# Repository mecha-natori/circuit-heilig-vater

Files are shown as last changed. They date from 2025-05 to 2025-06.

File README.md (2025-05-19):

# Heilig Vater

Heilig Vaterは[STM32F405RGT6]を使用した12V出力駆動用基板です。

## 仕様

| 機能 | 個数 | 備考 |
| :---: | ---: | :--- |
| MCU | 1 | [STM32F405RGT6] |
| ST-LINK | 1 | ピンアサインはSWD |
| CAN | 2 | 電源ピンは5V、Classic CANのみ対応、1系統から2個 |
| 12Vデジタル出力 | 14 | インジケータLED付き |
|  リセットスイッチ | 1 | |
| 5V-3.3Vレギュレータ | 1 | 外部電源からの供給用 |
| M.U氏の御尊顔 | 1 | 目が光る！(電源供給確認用(建前)) |
| 寸法(外形) | | 111mm x 86mm |
| 寸法(ネジ穴間) | | 100mm x 75mm |

## 名前の由来

**H**igh **V**oltageです。今回はひねくれてドイツ語にしてみました。\
Heilig Vater beobachtet dich.

## 使用フォント

- KiCad Font : シンボル名・部名
- Times New Roman : 右下基板名
- [UnifrakturMaguntia - Google Fonts] : 左下"Heilig Vater beobachtet dich."
- [機械彫刻用標準書体フォント] : その他テキスト

[stm32f405rgt6]: https://www.stmcu.jp/stm32/stm32f4/stm32f405415/12229
[unifrakturmaguntia - google fonts]: https://fonts.google.com/specimen/UnifrakturMaguntia
[機械彫刻用標準書体フォント]: https://font.kim

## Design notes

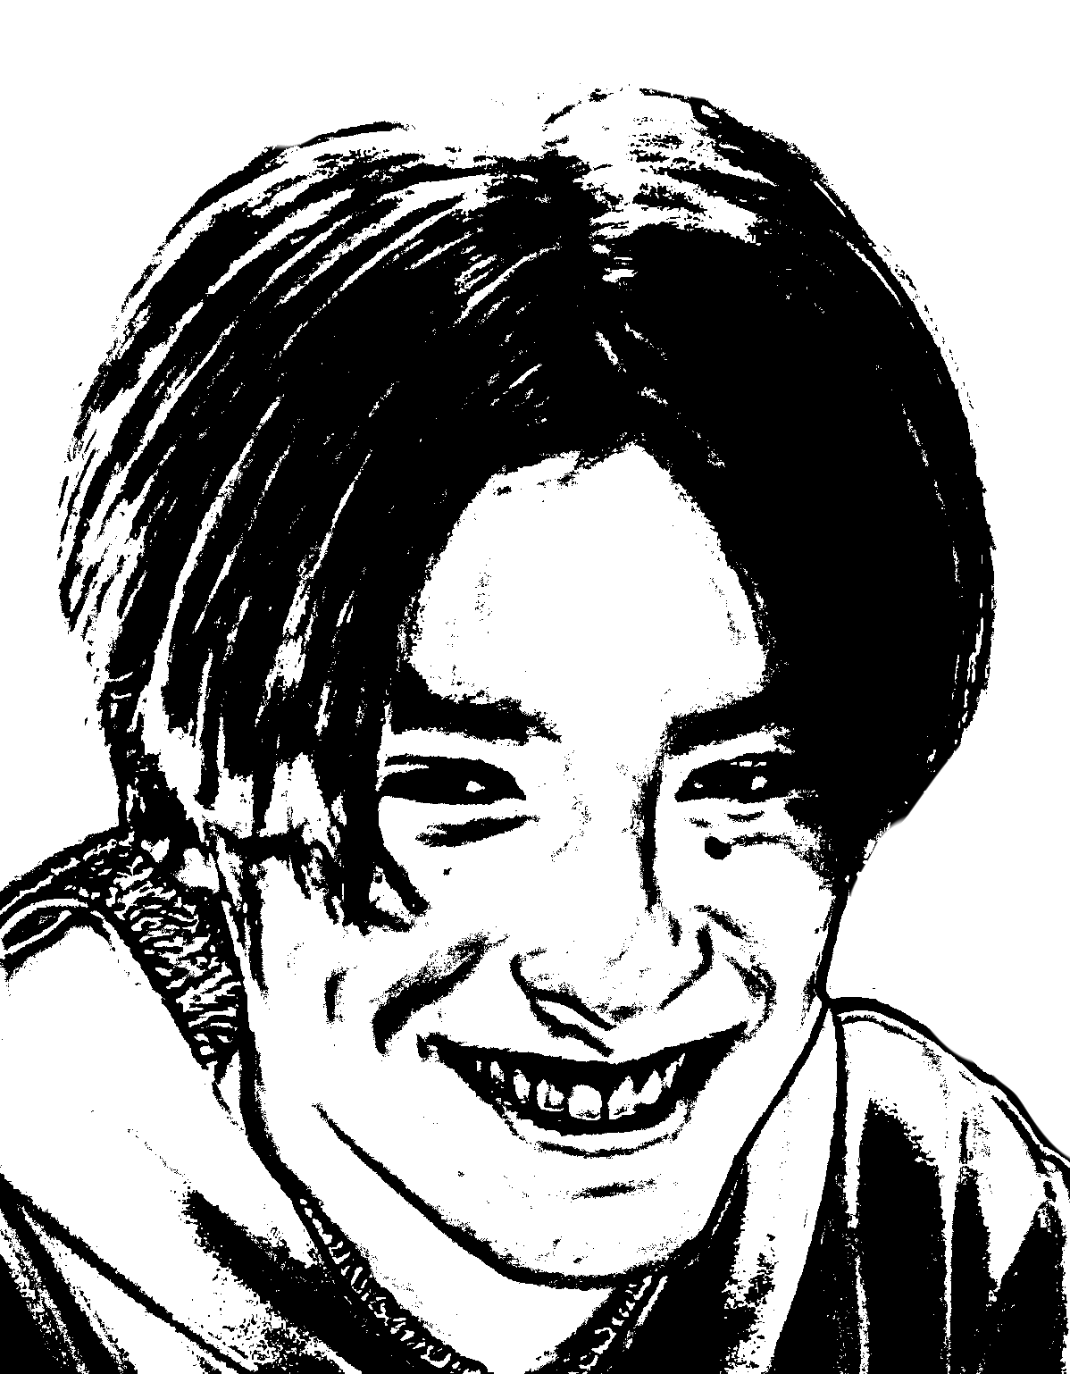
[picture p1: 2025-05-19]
m-u.png

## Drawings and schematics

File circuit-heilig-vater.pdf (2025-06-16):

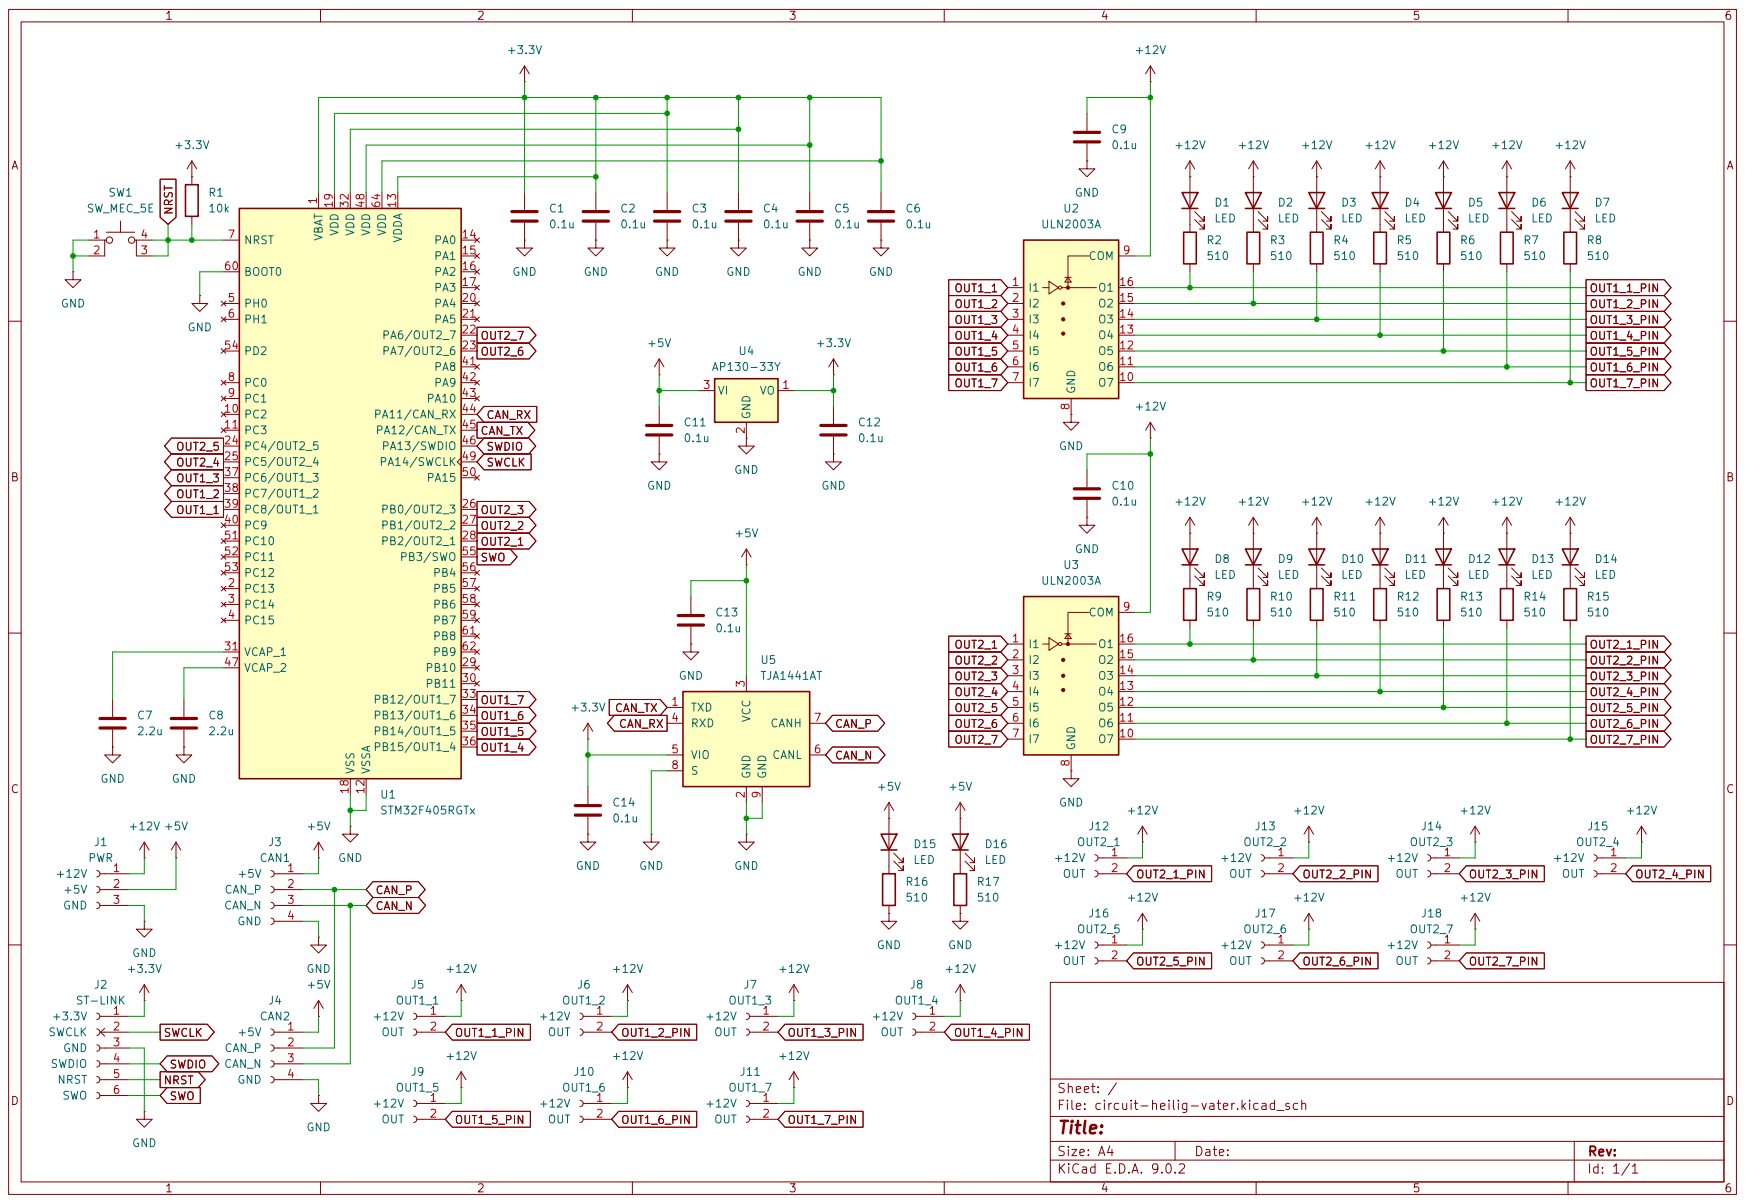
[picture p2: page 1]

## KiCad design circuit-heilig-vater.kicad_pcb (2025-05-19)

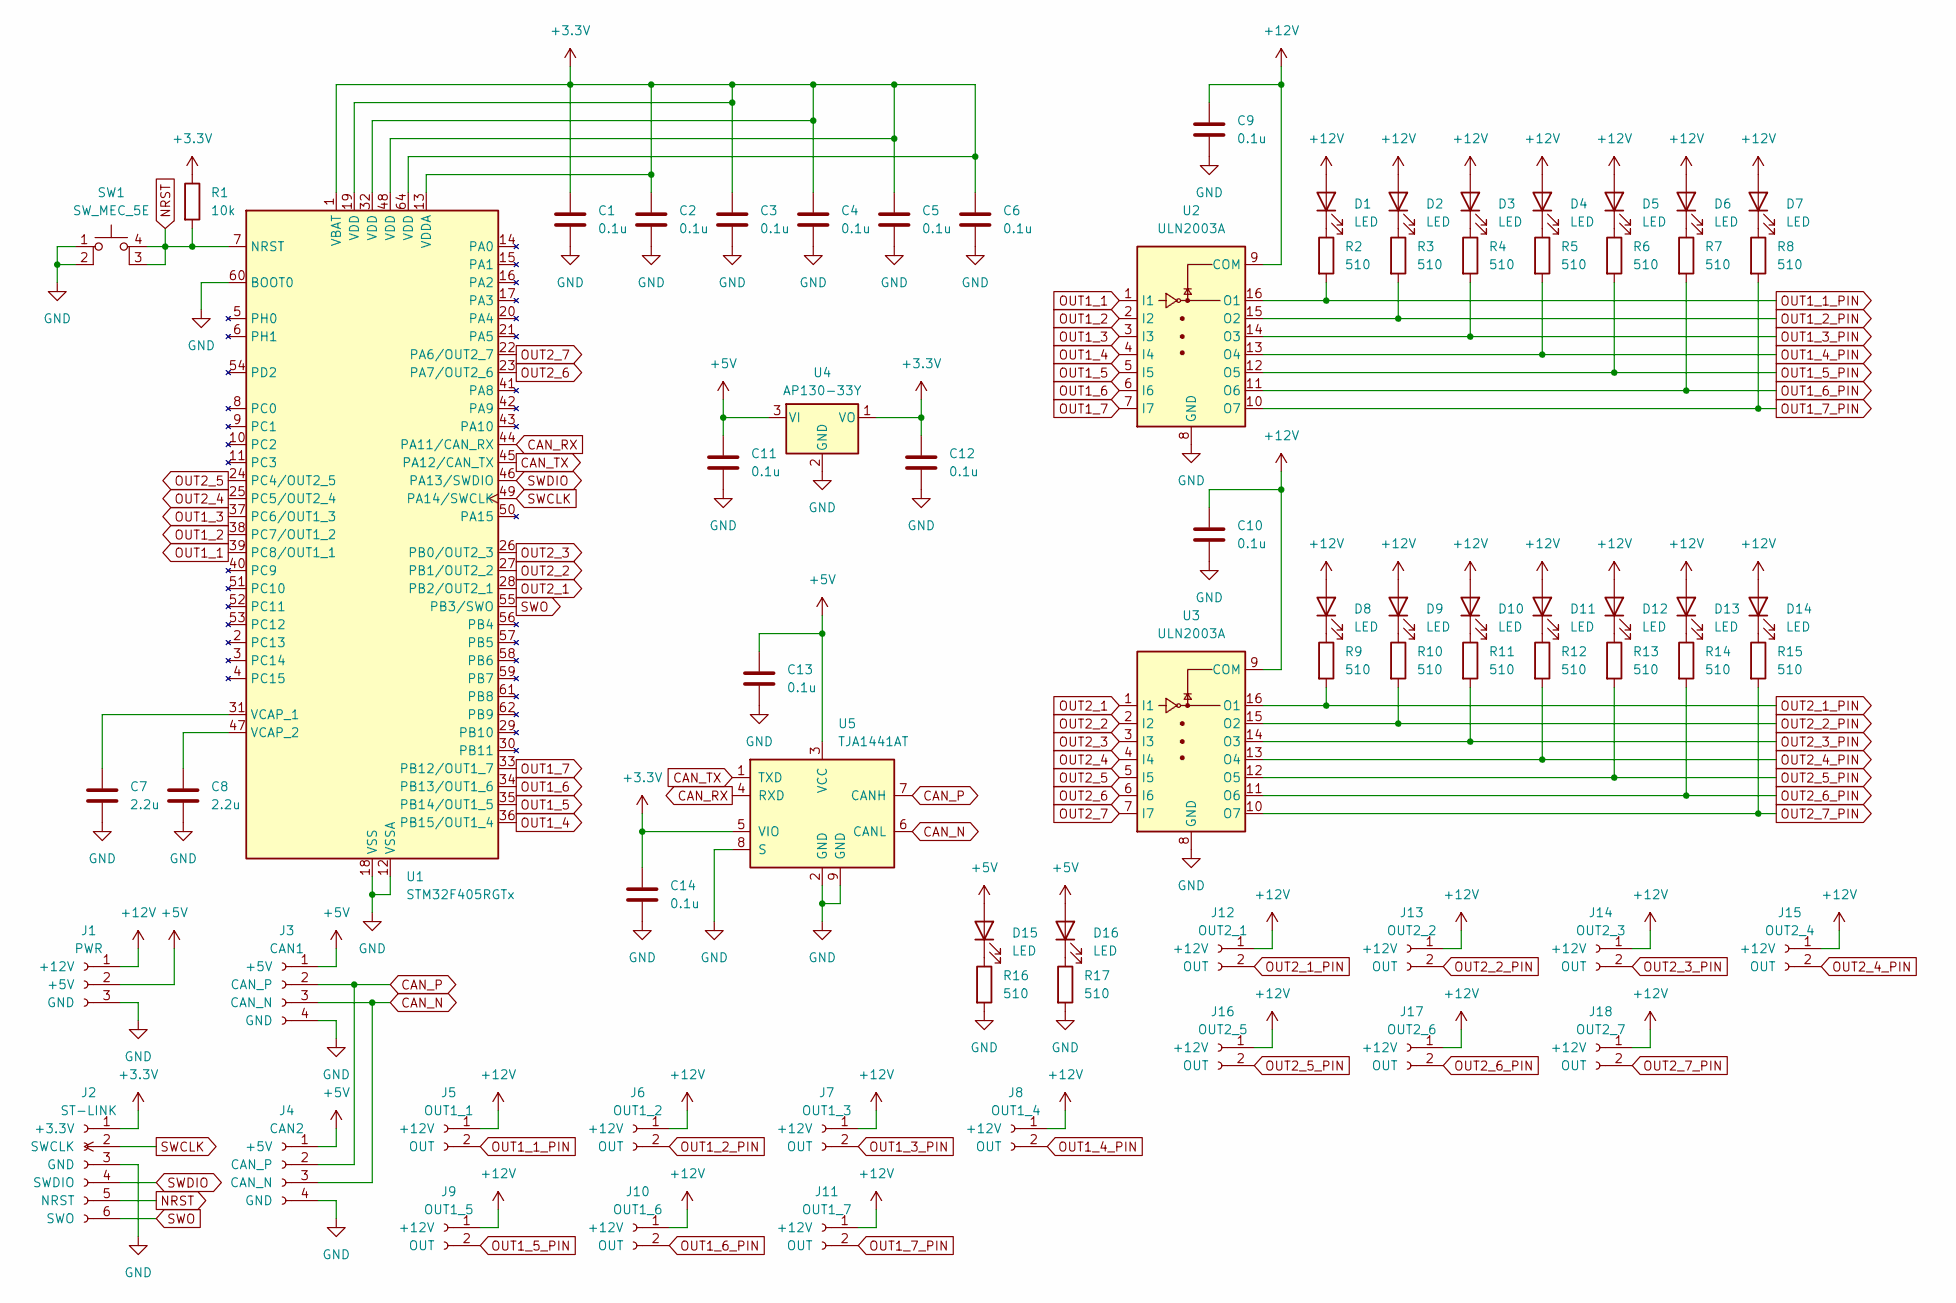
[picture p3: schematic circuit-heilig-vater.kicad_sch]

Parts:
C1, C2, C3, C4, C5, C6, C9, C10, C11, C12, C13, C14: 0.1u; C_0603_1608Metric_Pad1.08x0.95mm_HandSolder
C7, C8: 2.2u; C_0603_1608Metric_Pad1.08x0.95mm_HandSolder
D1, D2, D3, D4, D5, D6, D7, D8, D9, D10, D11, D12, D13, D14, D15, D16: LED; LED_0603_1608Metric_Pad1.05x0.95mm_HandSolder
J1: PWR; JST_XH_S3B-XH-A_1x03_P2.50mm_Horizontal
J2: ST-LINK; JST_ZH_B6B-ZR_1x06_P1.50mm_Vertical
J3: CAN1; JST_XA_B04B-XASK-1_1x04_P2.50mm_Vertical
J4: CAN2; JST_XA_B04B-XASK-1_1x04_P2.50mm_Vertical
J5: OUT1_1; JST_XH_B2B-XH-A_1x02_P2.50mm_Vertical
J6: OUT1_2; JST_XH_B2B-XH-A_1x02_P2.50mm_Vertical
J7: OUT1_3; JST_XH_B2B-XH-A_1x02_P2.50mm_Vertical
J8: OUT1_4; JST_XH_B2B-XH-A_1x02_P2.50mm_Vertical
J9: OUT1_5; JST_XH_B2B-XH-A_1x02_P2.50mm_Vertical
J10: OUT1_6; JST_XH_B2B-XH-A_1x02_P2.50mm_Vertical
J11: OUT1_7; JST_XH_B2B-XH-A_1x02_P2.50mm_Vertical
J12: OUT2_1; JST_XH_B2B-XH-A_1x02_P2.50mm_Vertical
J13: OUT2_2; JST_XH_B2B-XH-A_1x02_P2.50mm_Vertical
J14: OUT2_3; JST_XH_B2B-XH-A_1x02_P2.50mm_Vertical
J15: OUT2_4; JST_XH_B2B-XH-A_1x02_P2.50mm_Vertical
J16: OUT2_5; JST_XH_B2B-XH-A_1x02_P2.50mm_Vertical
J17: OUT2_6; JST_XH_B2B-XH-A_1x02_P2.50mm_Vertical
J18: OUT2_7; JST_XH_B2B-XH-A_1x02_P2.50mm_Vertical
R1: 10k; R_0603_1608Metric_Pad0.98x0.95mm_HandSolder
R2, R3, R4, R5, R6, R7, R8, R9, R10, R11, R12, R13, R14, R15, R16, R17: 510; R_0603_1608Metric_Pad0.98x0.95mm_HandSolder
SW1: SW_MEC_5E; tact
U1: STM32F405RGTx; LQFP-64_10x10mm_P0.5mm
U2, U3: ULN2003A; DIP-16_W7.62mm_LongPads
U4: AP130-33Y; SOT-89-3
U5: TJA1441AT; SOIC-8-1EP_3.9x4.9mm_P1.27mm_EP2.41x3.81mm_ThermalVias

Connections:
+3.3V: C1.1, C2.1, C3.1, C4.1, C5.1, C6.1, C12.1, C14.1, J2.1 (+3.3V), R1.1, U1.1 (VBAT), U1.13 (VDDA), U1.19 (VDD), U1.32 (VDD), U1.48 (VDD), U1.64 (VDD), U4.1 (VO), U5.5 (VIO)
+5V: C11.1, C13.1, D15.2 (A), D16.2 (A), J1.2 (+5V), J3.1 (+5V), J4.1 (+5V), U4.3 (VI), U5.3 (VCC)
+12V: C9.1, C10.1, D1.2 (A), D2.2 (A), D3.2 (A), D4.2 (A), D5.2 (A), D6.2 (A), D7.2 (A), D8.2 (A), D9.2 (A), D10.2 (A), D11.2 (A), D12.2 (A), D13.2 (A), D14.2 (A), J1.1 (+12V), J5.1 (+12V), J6.1 (+12V), J7.1 (+12V), J8.1 (+12V), J9.1 (+12V), J10.1 (+12V), J11.1 (+12V), J12.1 (+12V), J13.1 (+12V), J14.1 (+12V), J15.1 (+12V), J16.1 (+12V), J17.1 (+12V), J18.1 (+12V), U2.9 (COM), U3.9 (COM)
CAN_N: J3.3 (CAN_N), J4.3 (CAN_N), U5.6 (CANL)
CAN_P: J3.2 (CAN_P), J4.2 (CAN_P), U5.7 (CANH)
CAN_RX: U1.44 (PA11/CAN_RX), U5.4 (RXD)
CAN_TX: U1.45 (PA12/CAN_TX), U5.1 (TXD)
GND: C1.2, C2.2, C3.2, C4.2, C5.2, C6.2, C7.2, C8.2, C9.2, C10.2, C11.2, C12.2, C13.2, C14.2, J1.3 (GND), J2.3 (GND), J3.4 (GND), J4.4 (GND), R16.2, R17.2, SW1.1, SW1.2, U1.12 (VSSA), U1.18 (VSS), U1.60 (BOOT0), U1.63 (VSS), U2.8 (GND), U3.8 (GND), U4.2 (GND), U5.2 (GND), U5.8 (S), U5.9 (GND)
NRST: J2.5 (NRST), R1.2, SW1.3 (K), SW1.4 (A), U1.7 (NRST)
unnamed: D1.1 (K), R2.1
unnamed: D2.1 (K), R3.1
unnamed: D3.1 (K), R4.1
unnamed: D4.1 (K), R5.1
unnamed: D5.1 (K), R6.1
unnamed: D6.1 (K), R7.1
unnamed: D7.1 (K), R8.1
unnamed: D8.1 (K), R9.1
unnamed: D9.1 (K), R10.1
unnamed: D10.1 (K), R11.1
unnamed: D11.1 (K), R12.1
unnamed: D12.1 (K), R13.1
unnamed: D13.1 (K), R14.1
unnamed: D14.1 (K), R15.1
unnamed: D15.1 (K), R16.1
unnamed: D16.1 (K), R17.1
unnamed: C7.1, U1.31 (VCAP_1)
unnamed: C8.1, U1.47 (VCAP_2)
OUT1_1: U1.39 (PC8/OUT1_1), U2.1 (I1)
OUT1_1_PIN: J5.2 (OUT), R2.2, U2.16 (O1)
OUT1_2: U1.38 (PC7/OUT1_2), U2.2 (I2)
OUT1_2_PIN: J6.2 (OUT), R3.2, U2.15 (O2)
OUT1_3: U1.37 (PC6/OUT1_3), U2.3 (I3)
OUT1_3_PIN: J7.2 (OUT), R4.2, U2.14 (O3)
OUT1_4: U1.36 (PB15/OUT1_4), U2.4 (I4)
OUT1_4_PIN: J8.2 (OUT), R5.2, U2.13 (O4)
OUT1_5: U1.35 (PB14/OUT1_5), U2.5 (I5)
OUT1_5_PIN: J9.2 (OUT), R6.2, U2.12 (O5)
OUT1_6: U1.34 (PB13/OUT1_6), U2.6 (I6)
OUT1_6_PIN: J10.2 (OUT), R7.2, U2.11 (O6)
OUT1_7: U1.33 (PB12/OUT1_7), U2.7 (I7)
OUT1_7_PIN: J11.2 (OUT), R8.2, U2.10 (O7)
OUT2_1: U1.28 (PB2/OUT2_1), U3.1 (I1)
OUT2_1_PIN: J12.2 (OUT), R9.2, U3.16 (O1)
OUT2_2: U1.27 (PB1/OUT2_2), U3.2 (I2)
OUT2_2_PIN: J13.2 (OUT), R10.2, U3.15 (O2)
OUT2_3: U1.26 (PB0/OUT2_3), U3.3 (I3)
OUT2_3_PIN: J14.2 (OUT), R11.2, U3.14 (O3)
OUT2_4: U1.25 (PC5/OUT2_4), U3.4 (I4)
OUT2_4_PIN: J15.2 (OUT), R12.2, U3.13 (O4)
OUT2_5: U1.24 (PC4/OUT2_5), U3.5 (I5)
OUT2_5_PIN: J16.2 (OUT), R13.2, U3.12 (O5)
OUT2_6: U1.23 (PA7/OUT2_6), U3.6 (I6)
OUT2_6_PIN: J17.2 (OUT), R14.2, U3.11 (O6)
OUT2_7: U1.22 (PA6/OUT2_7), U3.7 (I7)
OUT2_7_PIN: J18.2 (OUT), R15.2, U3.10 (O7)
SWCLK: J2.2 (SWCLK), U1.49 (PA14/SWCLK)
SWDIO: J2.4 (SWDIO), U1.46 (PA13/SWDIO)
SWO: J2.6 (SWO), U1.55 (PB3/SWO)

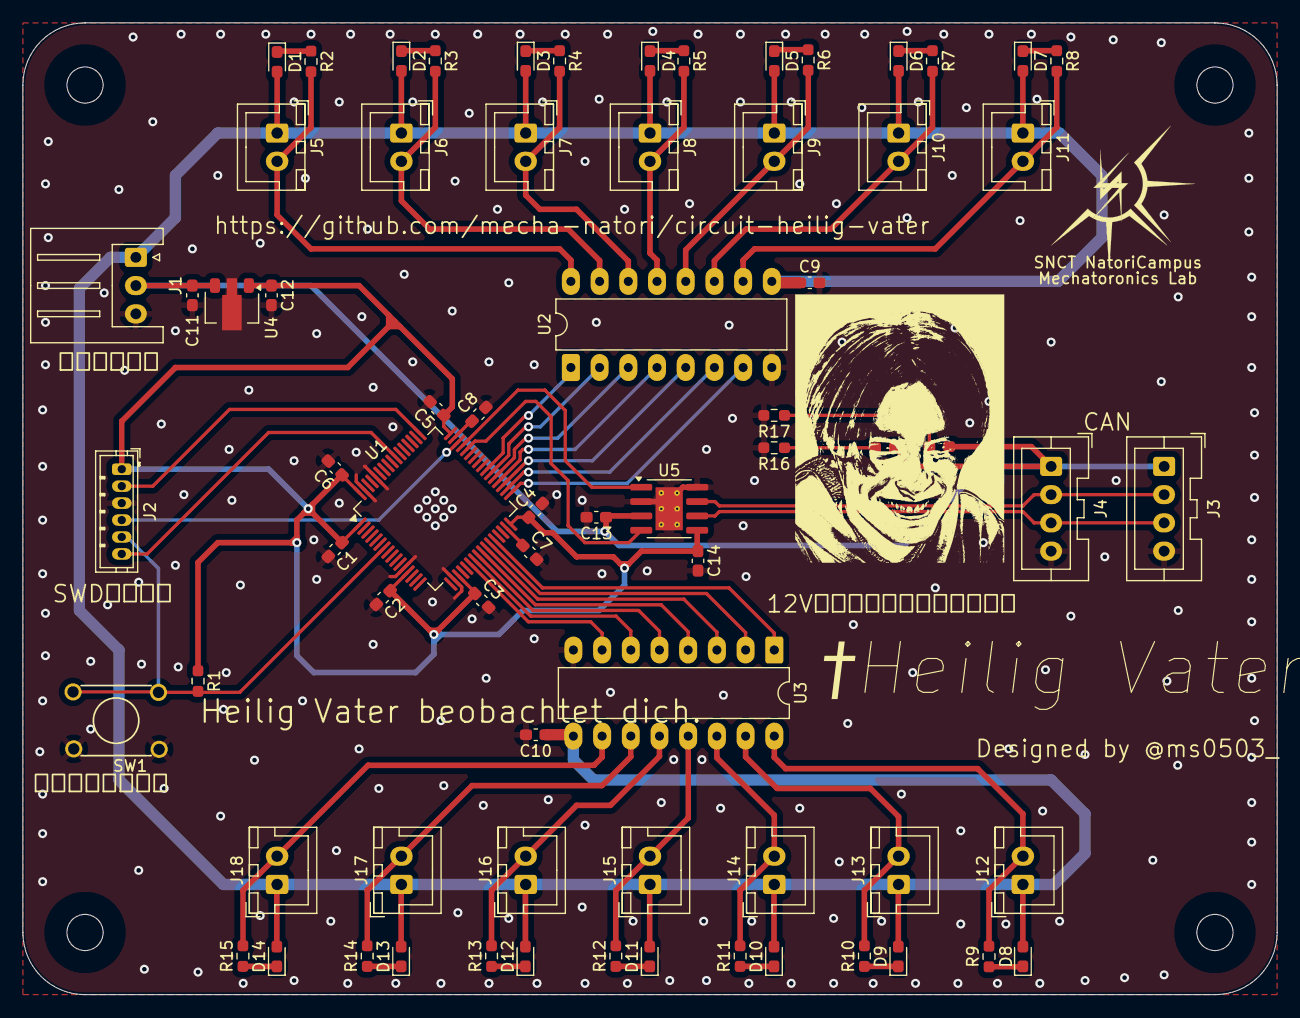
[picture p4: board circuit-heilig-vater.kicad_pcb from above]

Board: 2 copper layers, 111.0 x 86.0 mm, 75 parts (0 on the bottom side), 58 nets.

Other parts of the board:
 : holeφ3.2
 #2,  #3,  #4: holeφ3.2
